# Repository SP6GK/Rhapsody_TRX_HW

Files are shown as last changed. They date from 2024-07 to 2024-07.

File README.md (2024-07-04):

# Rhapsody Project

Rhapsody is an ongoing project focused on the development of a modular amateur radio transceiver. The current version of the project features the zero-IF board, which utilizes two balanced Tayloe mixers to convert 1-30 MHz RF signals into baseband IQ that can be processed by an ADC, and to convert baseband IQ generated by a DAC into output RF, implementing a simplex HF transceiver.

In this repository, you can find the first module developed for the Rhapsody project - the IQ board. This PCB implements two balanced Tayloe mixers (or product detectors if you prefer) to implement both transmit and receive paths for an SDR transceiver. Together with a microcontroller and ADC+DAC (or a PC with a sound card), you can create a working HF software-defined transceiver. Special care was put into the design to provide the best IQ balance for superb opposite sideband attenuation.

I have presented more measurements and theory of operation on my personal website: [Description of Rhapsody project on SP6GK.com](https://www.sp6gk.com/Rhapsody_IQ_Board.html). Bare in mind that these results were possible thanks to low tolerance components in the feedback loops of the op amps and software tuning.

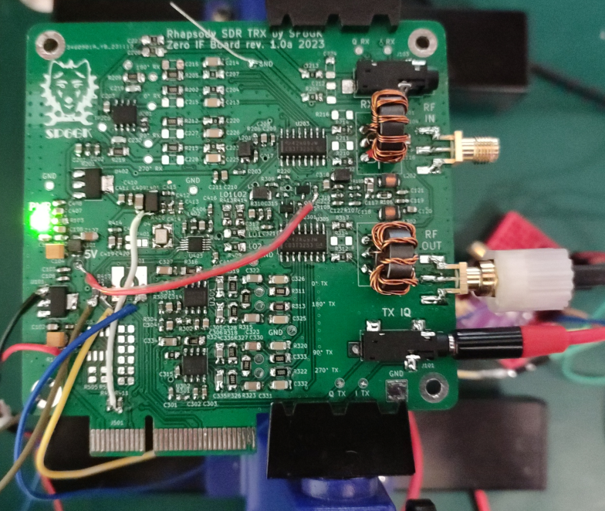
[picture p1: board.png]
Assembled PCB


The current version of the IQ board is designed for testability. Zero Ohm resistors are implemented as jumpers so that different configurations of RF transformers can be tested. If the value of a resistor is not provided, it is most likely not to be populated (DNP). On the other hand, the zero-Ohm resistors indicate the default option.
RF transformers were wound on FT37-43.

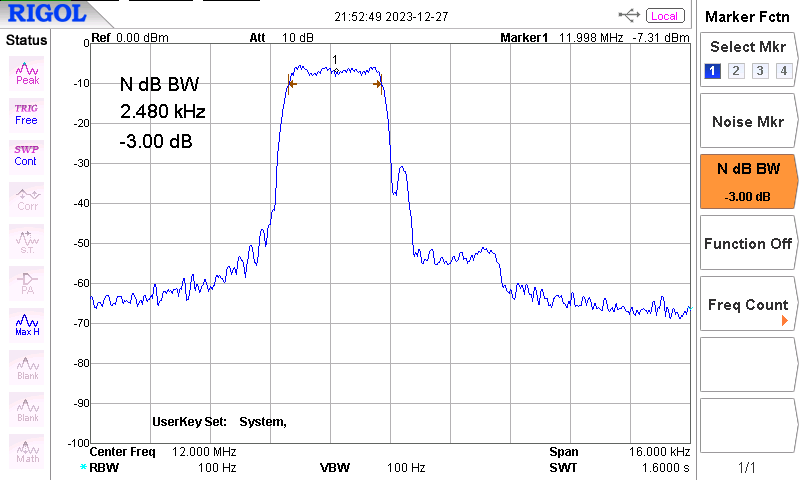
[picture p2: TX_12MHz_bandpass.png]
Single tone SSB at 12 MHz TX

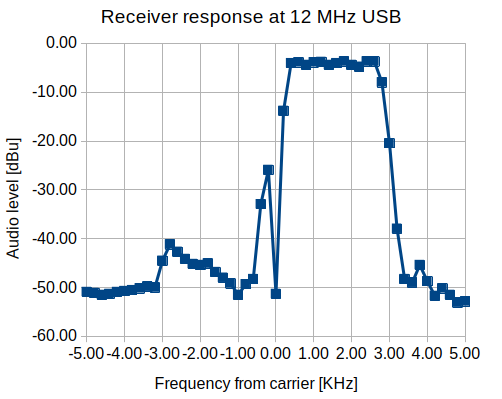
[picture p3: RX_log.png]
Receiver selectivity


The above results were obtained with my software running on an STM32F407 with a 24-bit 48 KHz ADC/DAC on the I2S interface. [Link to software repository](https://github.com/SP6GK/Rhapsody_TRX_SW)

**Experimental features include:**
- Option to include an additional active LPF in the IQ signal path before the ADC (better spurious image rejection and better anti-aliasing, but may cause worse IQ imbalance; not tested yet)
- Additional passive RC LPF before the RX op amps
- 2.5V reference created by impedance buffer - higher current output for the 2.5V rail should provide even better stability
- External oscillator can be used with a single-ended input. A Johnson Counter then creates an IQ LO. This solution limits the operating frequency to 1/4 of the maximum frequency of the 74xx74 chip used. The onboard PLL can provide an LO signal up to 100 MHz, and its reference is a TCXO or a simple crystal.

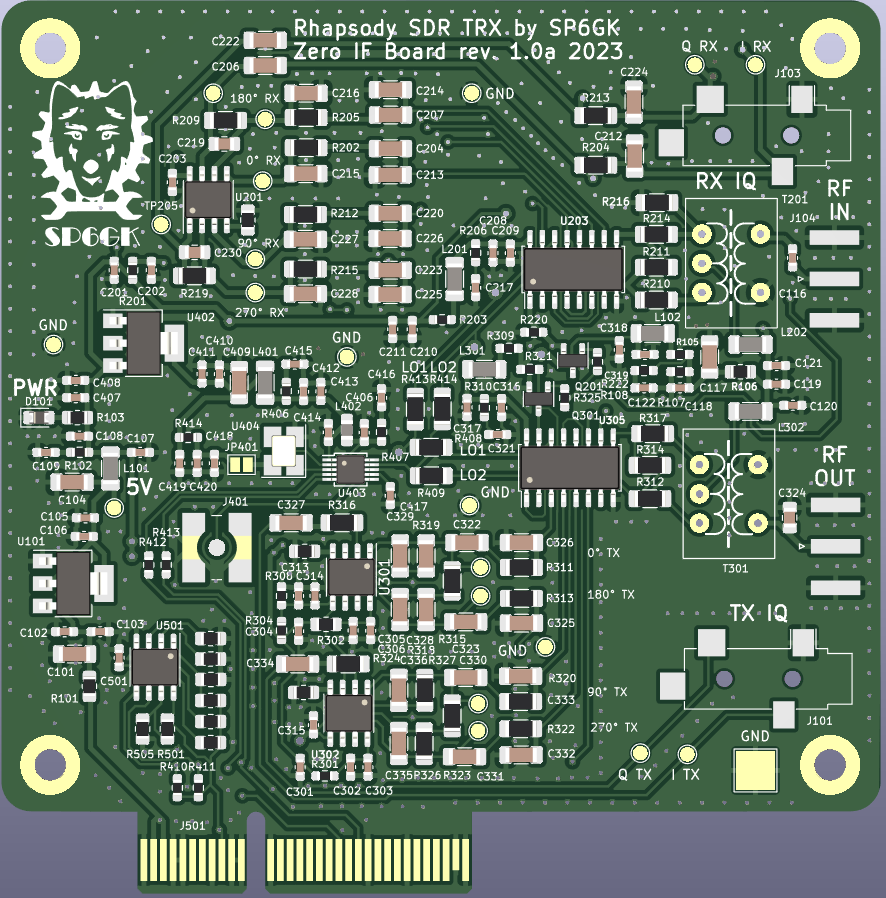
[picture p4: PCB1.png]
Front of the PCB

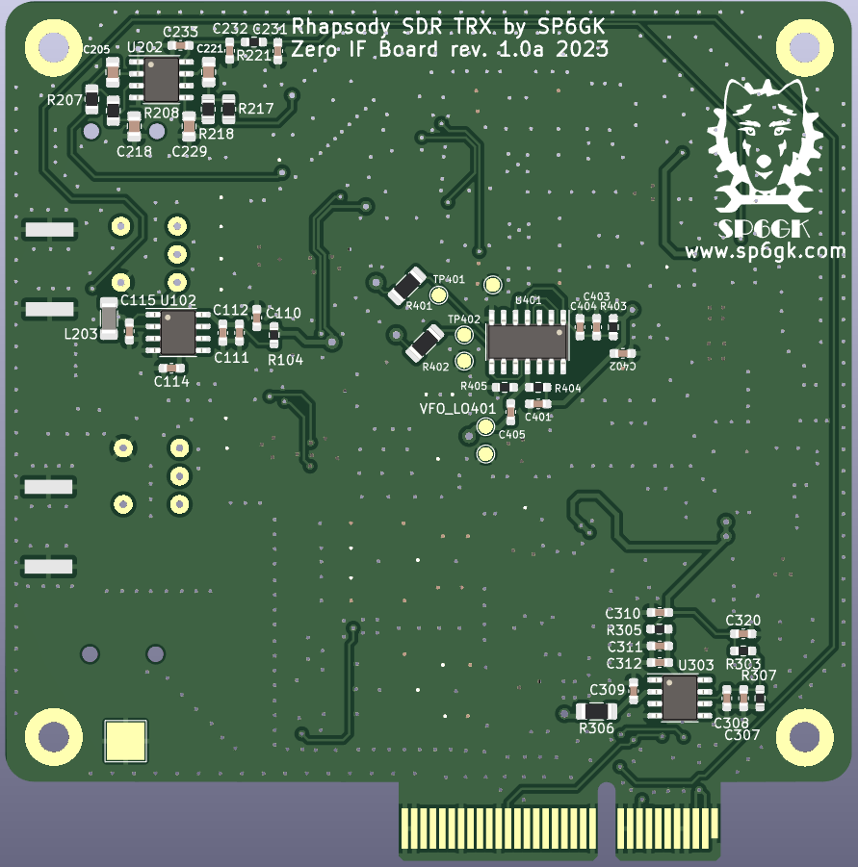
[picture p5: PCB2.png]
Back of the PCB


**How does it work?**
I recommend the following resources if you want to understand more about the hardware behind this project:
- **Best place to learn about the Tayloe mixer** by Dan Tayloe, [Ultra Low Noise, High Performance, Zero IF Quadrature Product Detector and Preamplifier](https://norcalqrp.org/files/Tayloe_mixer_x3a.pdf)
- **Further description of SDR** by Gerald Youngblood, [A Software-Defined Radio for the Masses](https://www.arrl.org/files/file/Technology/tis/info/pdf/020708qex013.pdf)

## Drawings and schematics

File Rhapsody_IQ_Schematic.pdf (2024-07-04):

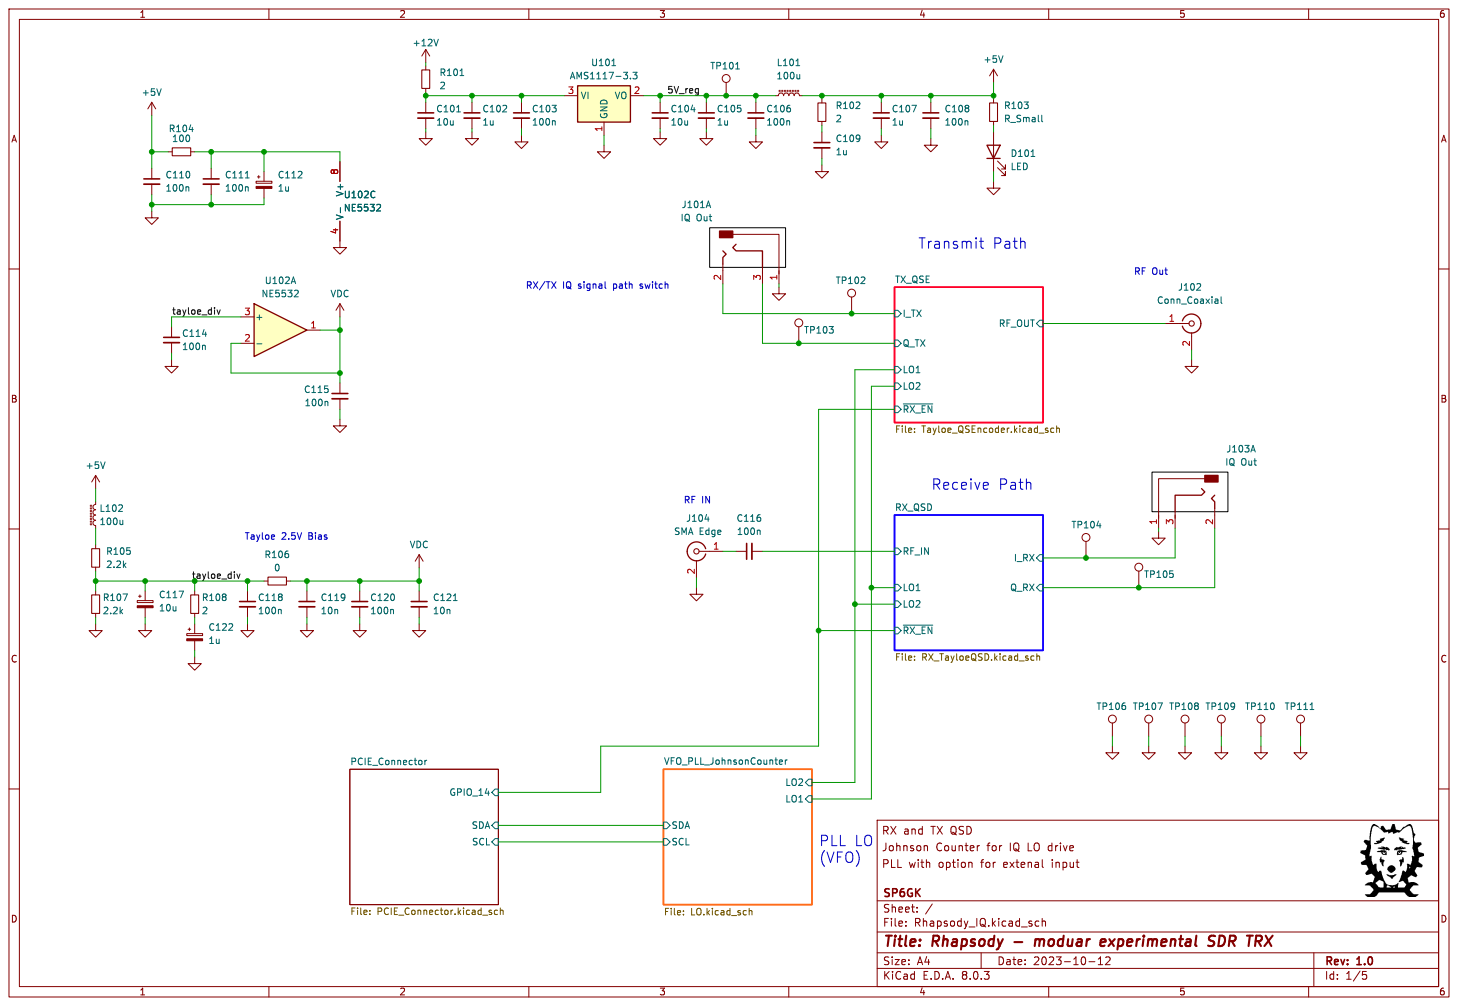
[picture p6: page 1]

RX/TX IQ signal path switch

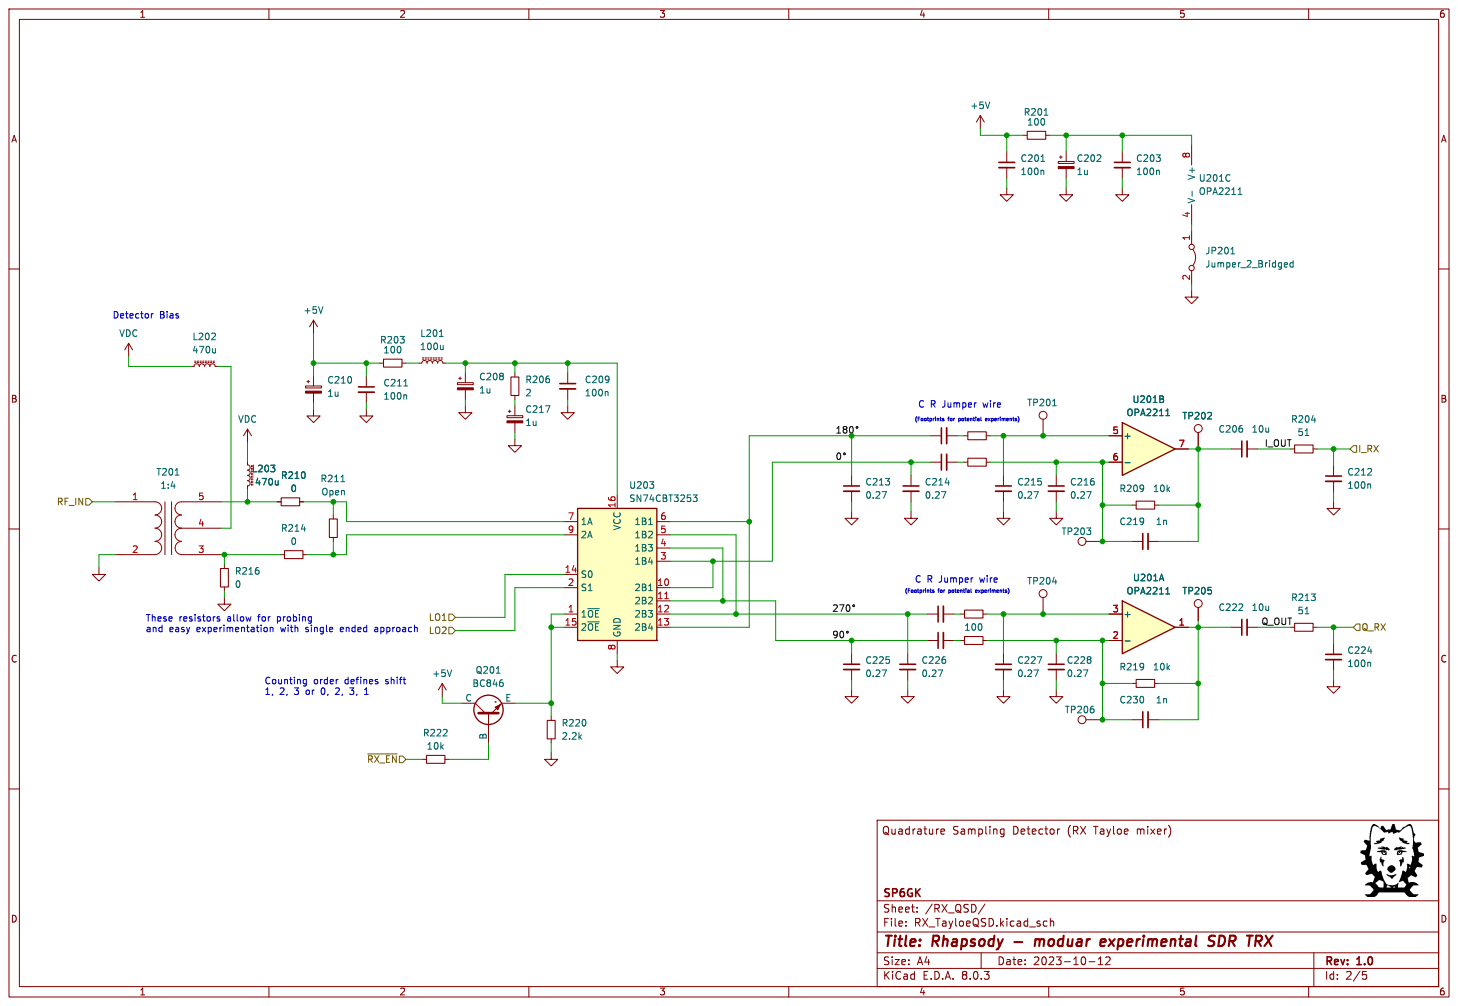
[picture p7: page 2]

Counting order defines shift 1, 2, 3 or 0, 2, 3, 1

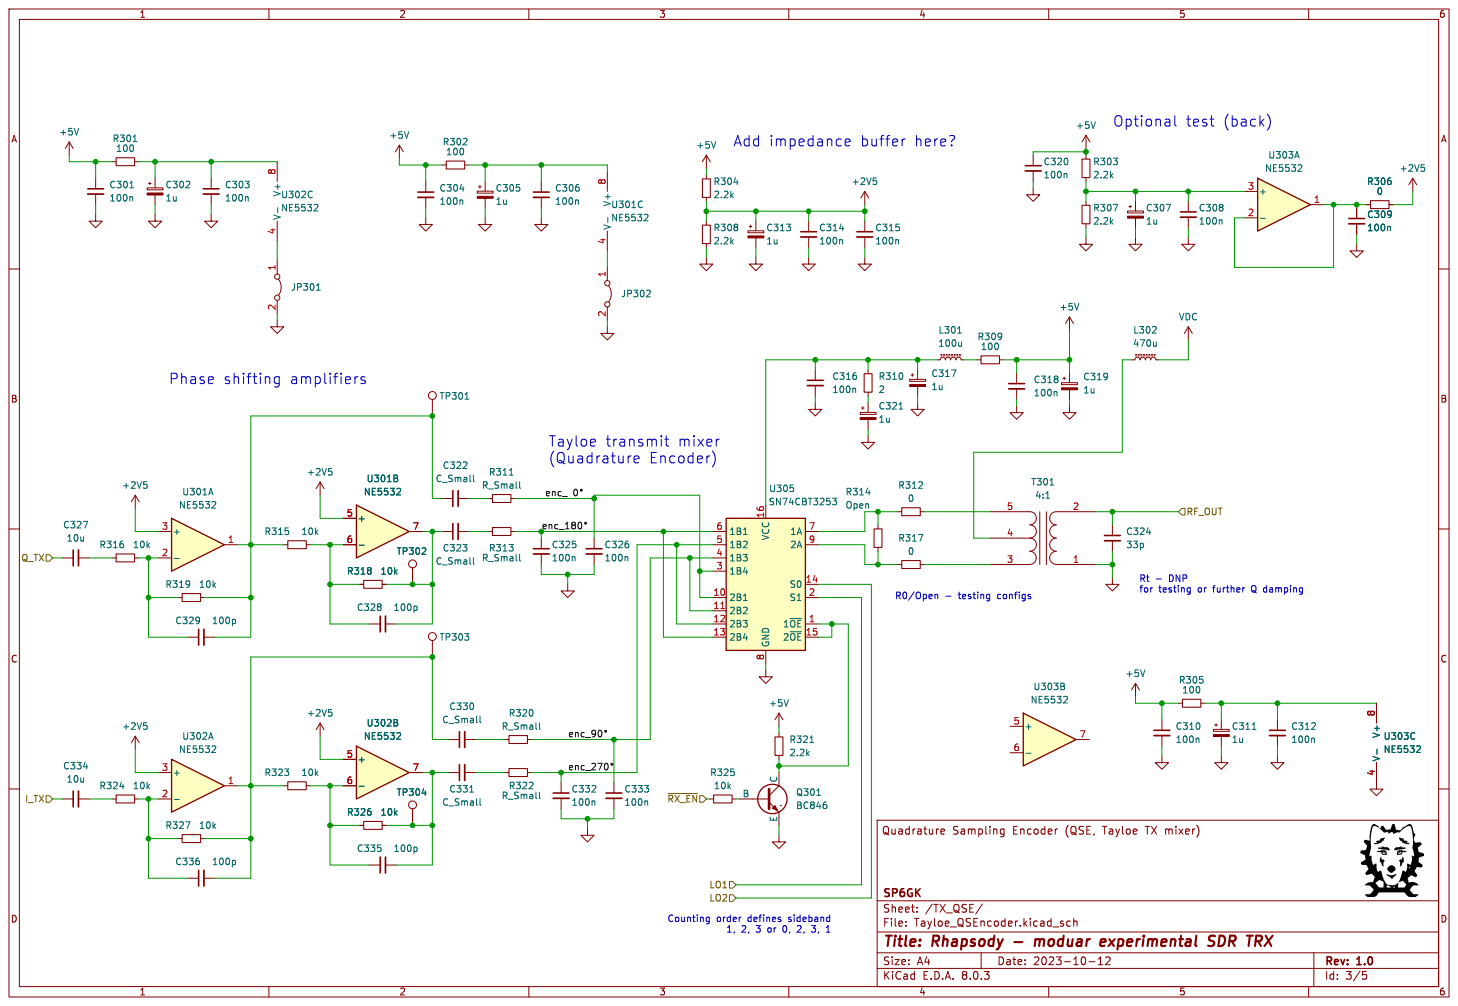
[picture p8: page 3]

for testing or further Q damping

Counting order defines sideband

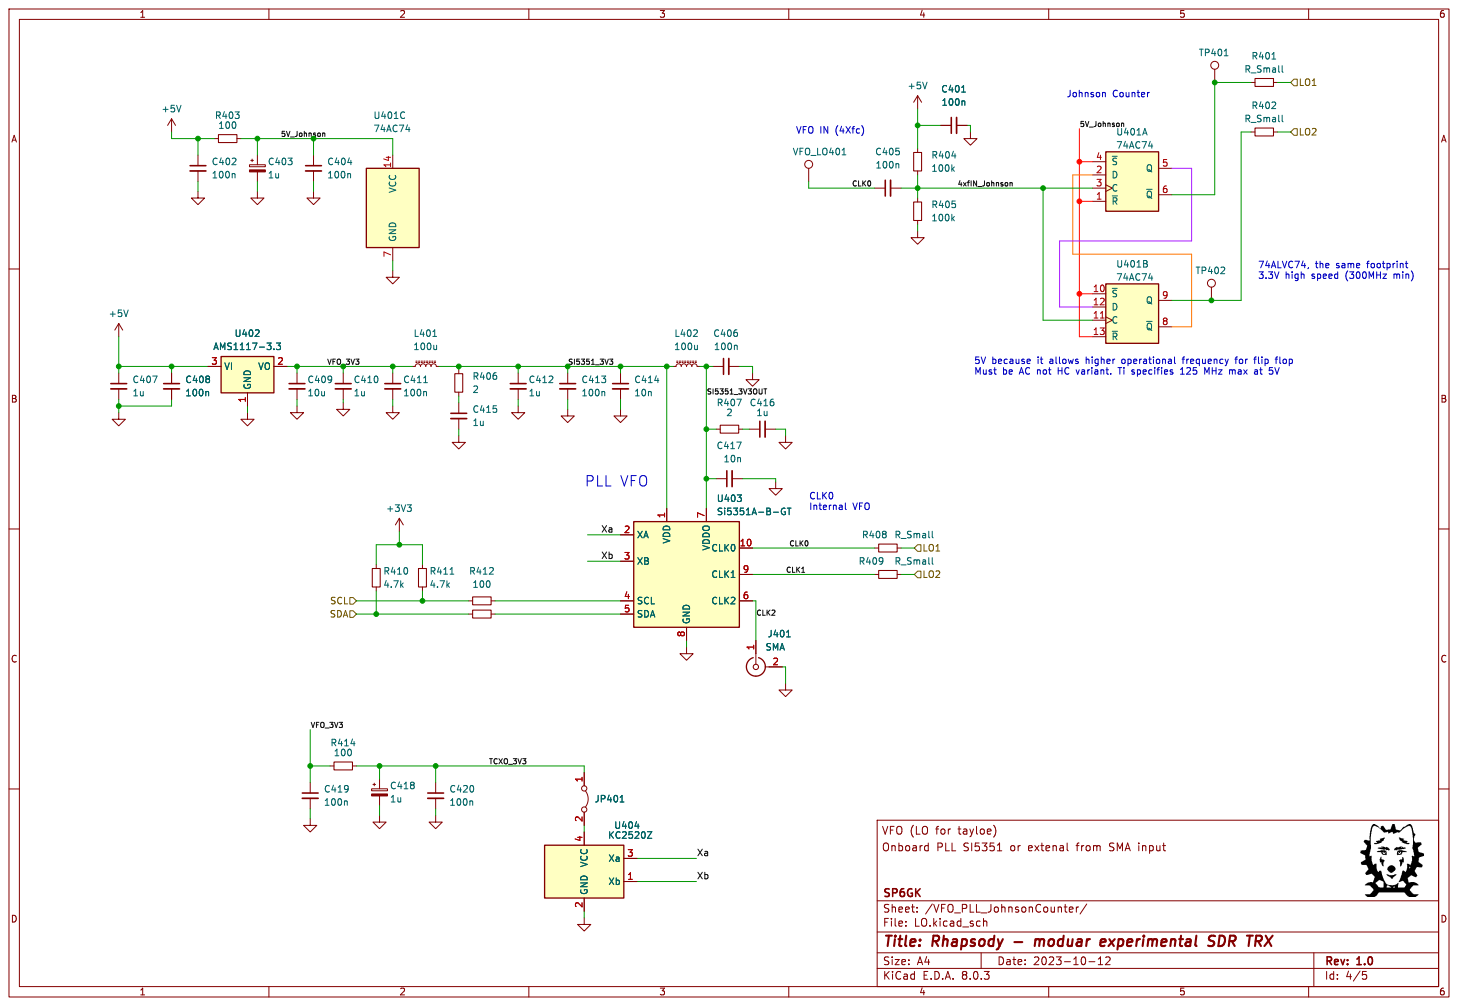
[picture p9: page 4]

74ALVC74, the same footprint 3.3V high speed (300MHz min) Johnson Counter PLL VFO

1 CLK0 10 XA 2 XB 3 SCL 4 SDA 5 CLK2 6 VDDO

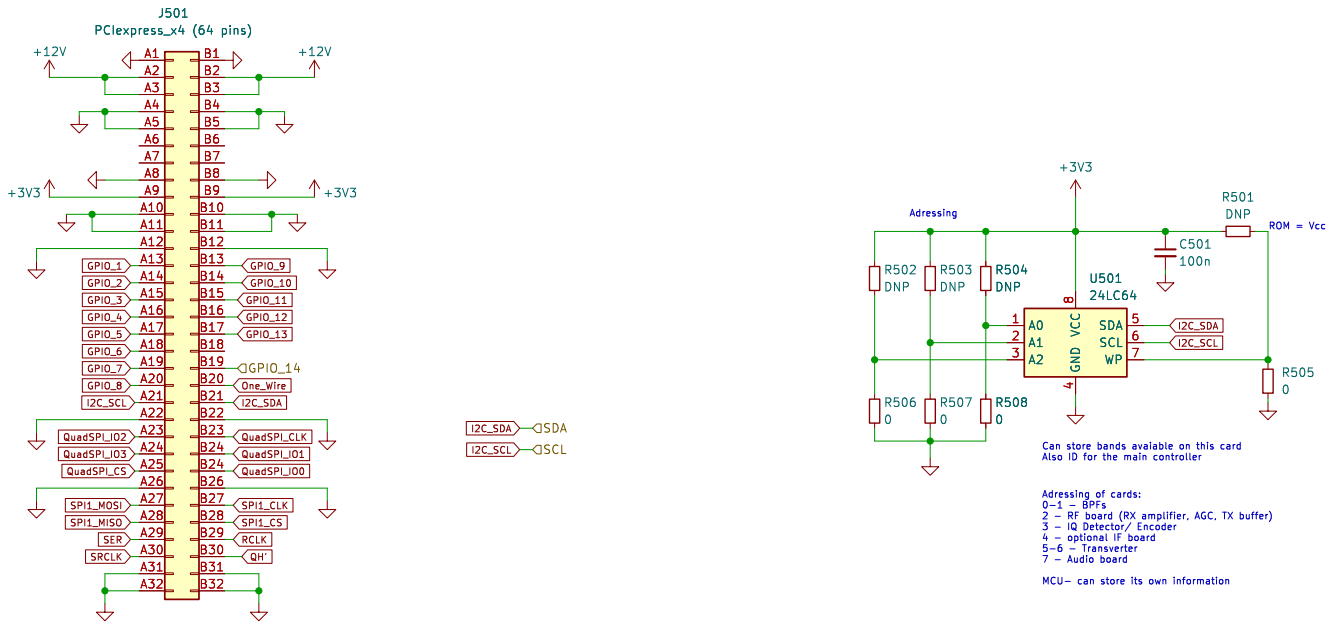
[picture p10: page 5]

4 SDA 5 SCL 6 WP 7 VCC

Id: 5/5 Title: File: PCIE_Connector.kicad_sch Sheet: /PCIE_Connector/

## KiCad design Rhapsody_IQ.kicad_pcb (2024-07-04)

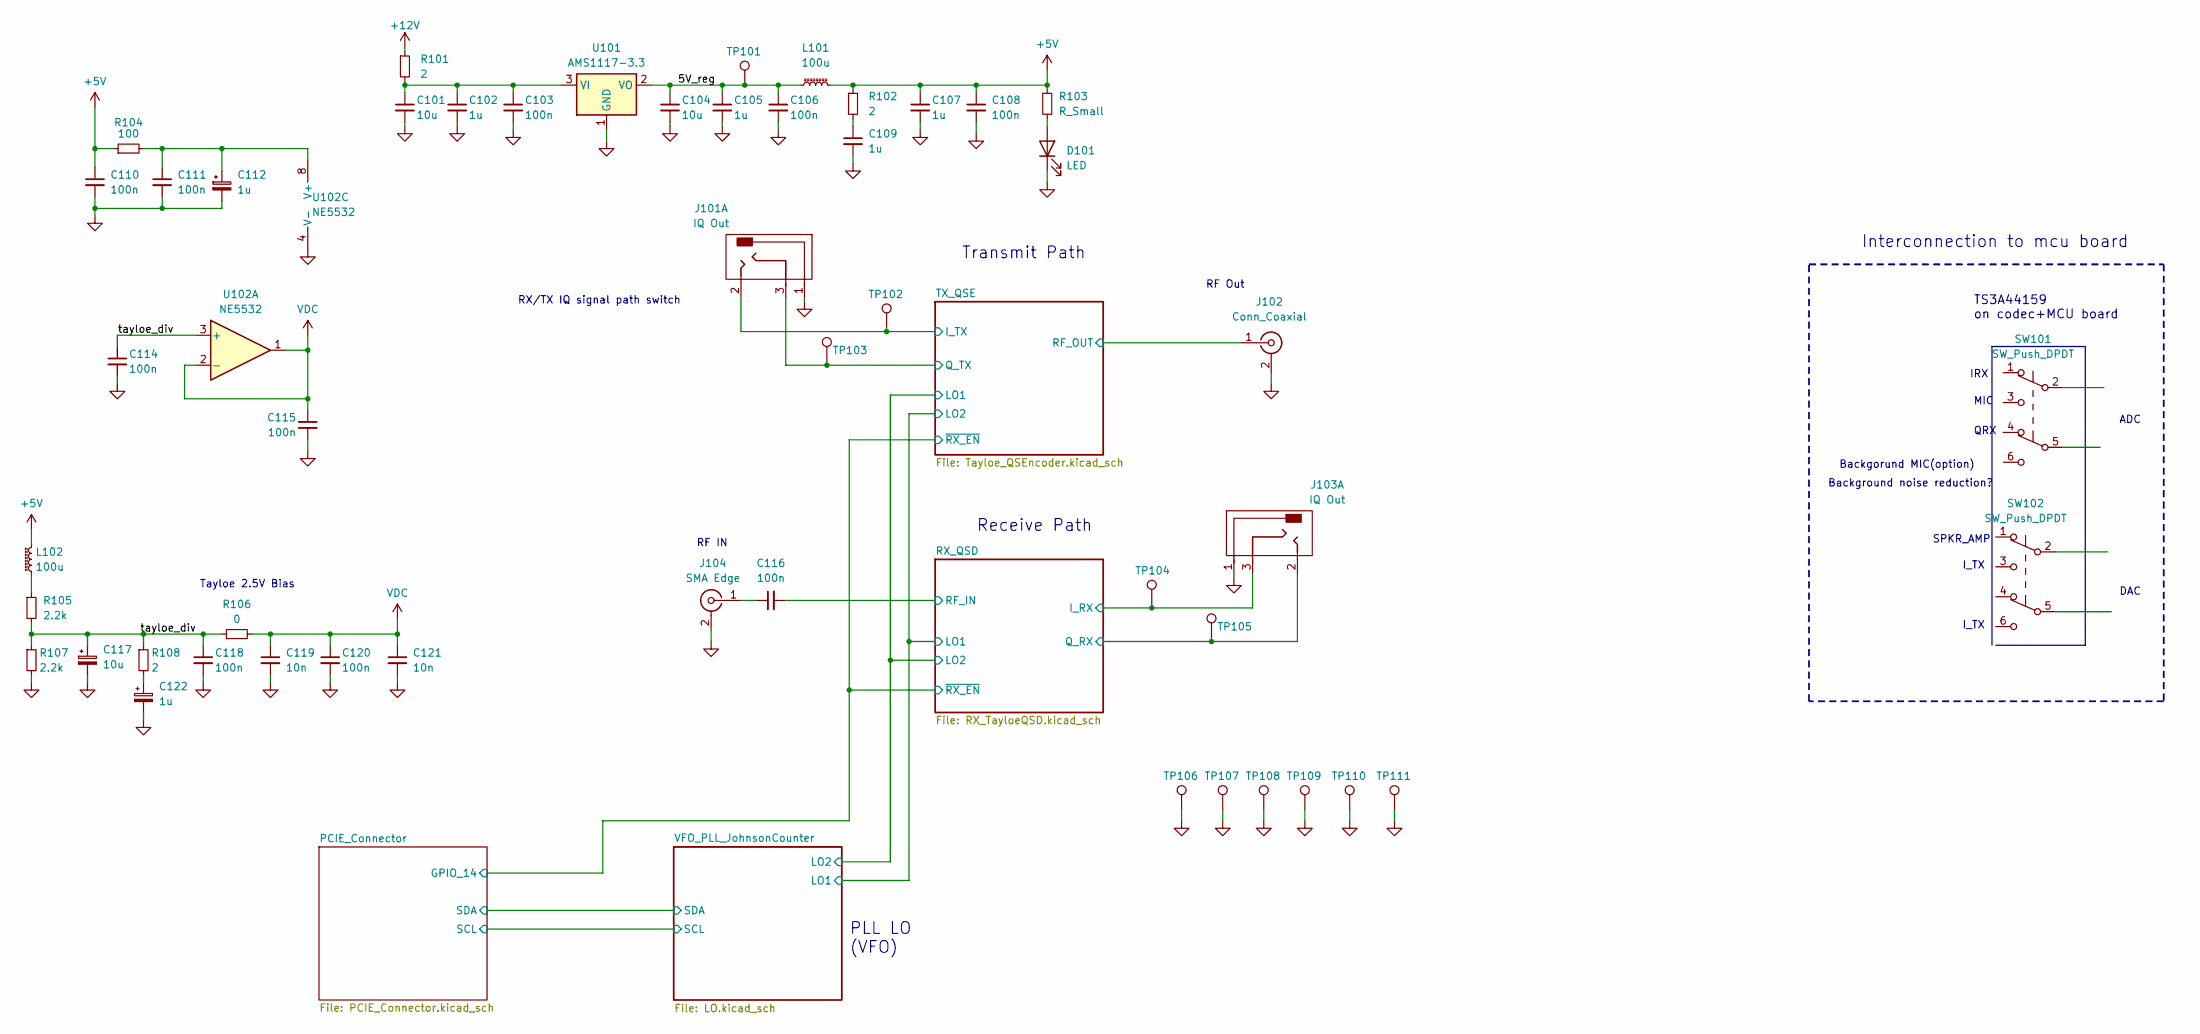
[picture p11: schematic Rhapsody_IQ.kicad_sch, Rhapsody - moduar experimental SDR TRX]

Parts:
C101, C104, C117: 10u; C_1206_3216Metric_Pad1.33x1.80mm_HandSolder
C102, C105, C107, C109, C112, C122: 1u; C_0603_1608Metric_Pad1.08x0.95mm_HandSolder
C103, C106, C108, C110, C111, C114, C115, C116, C118, C120: 100n; C_0603_1608Metric_Pad1.08x0.95mm_HandSolder
C119, C121: 10n; C_0603_1608Metric_Pad1.08x0.95mm_HandSolder
D101: LED; D_0805_2012Metric_Pad1.15x1.40mm_HandSolder
J101, J103: IQ Out; Jack_3.5mm_CUI_SJ-3524-SMT_Horizontal
J102: Conn_Coaxial; SMA_Amphenol_132289_EdgeMount
J104: SMA Edge; SMA_Amphenol_132289_EdgeMount
L101, L102: 100u; L_1206_3216Metric_Pad1.22x1.90mm_HandSolder
R101: 2; R_0805_2012Metric_Pad1.20x1.40mm_HandSolder
R102, R108: 2; R_0603_1608Metric_Pad0.98x0.95mm_HandSolder
R103: R_Small; R_0805_2012Metric_Pad1.20x1.40mm_HandSolder
R104: 100; R_0603_1608Metric_Pad0.98x0.95mm_HandSolder
R105, R107: 2.2k; R_0603_1608Metric_Pad0.98x0.95mm_HandSolder
R106: 0; R_0805_2012Metric_Pad1.20x1.40mm_HandSolder
SW101, SW102: SW_Push_DPDT
TP101, TP102, TP103, TP104, TP105, TP106, TP107, TP108, TP109: TestPoint; TestPoint_Pad_D1.5mm
TP110, TP111: TestPoint; TestPoint_Pad_4.0x4.0mm
U101: AMS1117-3.3; SOT-223-3_TabPin2
U102: NE5532; SOIC-8_3.9x4.9mm_P1.27mm

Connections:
+5V: C107.1, C108.1, C110.1, L101.2, L102.2, R102.1, R103.1, R104.1; also elsewhere on the board
+12V: R101.1; also elsewhere on the board
/5V_reg: C104.1, C105.1, C106.1, L101.1, TP101.1, U101.2 (VO)
/RX_QSD/I_RX: J103.3, TP104.1; also elsewhere on the board
/RX_QSD/Q_RX: J103.2, TP105.1; also elsewhere on the board
/RX_QSD/RF_IN: C116.2; also elsewhere on the board
/TX_QSE/I_TX: J101.2, TP102.1; also elsewhere on the board
/TX_QSE/Q_TX: J101.3, TP103.1; also elsewhere on the board
/TX_QSE/RF_OUT: J102.1 (In); also elsewhere on the board
/tayloe_div: C114.1, C117.1, C118.1, R105.2, R106.1, R107.1, R108.1, U102.3 (+)
GND: C101.2, C102.2, C103.2, C104.2, C105.2, C106.2, C107.2, C108.2, C109.2, C110.2, C111.2, C112.2, C114.2, C115.2, C117.2, C118.2, C119.2, C120.2, C121.2, C122.2, D101.1 (K), J101.1, J102.2 (Ext), J103.1, J104.2 (Ext), R107.2, TP106.1, TP107.1, TP108.1, TP109.1, TP110.1, TP111.1, U101.1 (GND), U102.4 (V-); also elsewhere on the board
unnamed: C109.1, R102.2
unnamed: C122.1, R108.2
unnamed: D101.2 (A), R103.2
unnamed: C116.1, J104.1 (In)
unnamed: L102.1, R105.1
unnamed: C101.1, C102.1, C103.1, R101.2, U101.3 (VI)
unnamed: C111.1, C112.1, R104.2, U102.8 (V+)
VDC: C115.1, C119.1, C120.1, C121.1, R106.2, U102.1, U102.2 (-); also elsewhere on the board

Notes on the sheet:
RF IN
DAC
Interconnection to mcu board
Backgorund MIC(option)
RF Out
RX/TX IQ signal path switch
Receive Path
Background noise reduction?
I_TX
SPKR_AMP
ADC
PLL LO (VFO)
TS3A44159 on codec+MCU board
IRX
Transmit Path
Tayloe 2.5V Bias
MIC
QRX

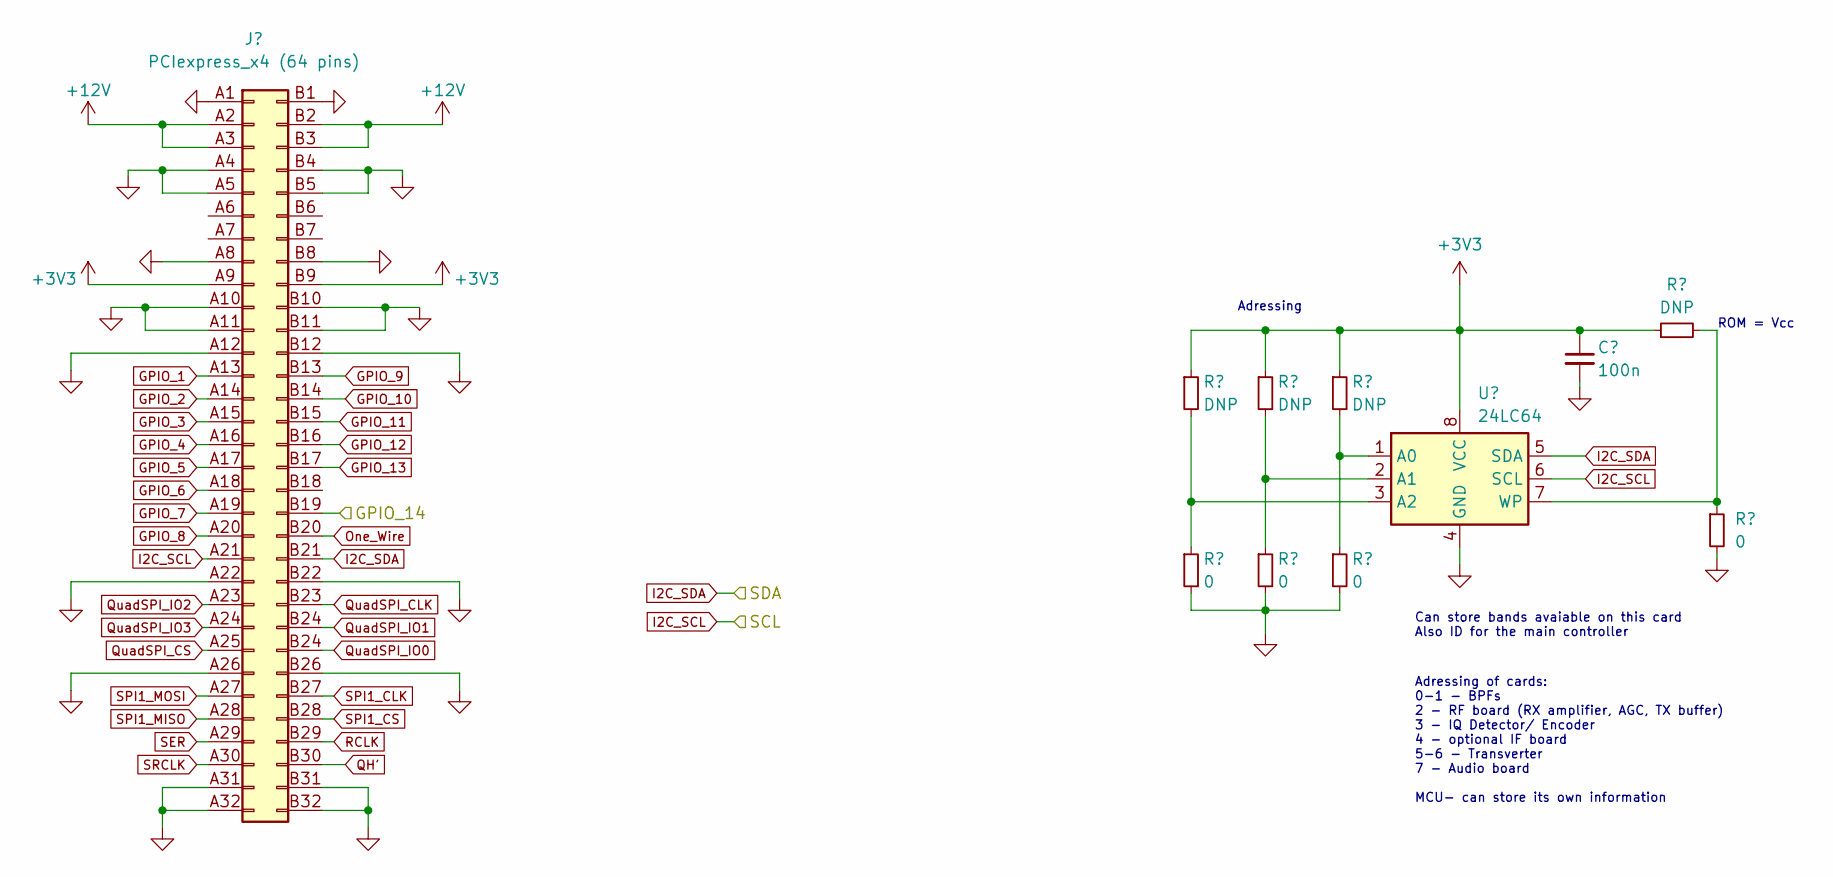
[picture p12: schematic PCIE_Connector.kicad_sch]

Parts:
C501: 100n; C_0603_1608Metric_Pad1.08x0.95mm_HandSolder
J501: PCIexpress_x4 (64 pins); BUS_PCIexpress_x4
R501, R502, R503, R504: DNP; R_0805_2012Metric_Pad1.20x1.40mm_HandSolder
R505, R506, R507, R508: 0; R_0805_2012Metric_Pad1.20x1.40mm_HandSolder
U501: 24LC64; SOIC-8_3.9x4.9mm_P1.27mm

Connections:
+3V3: C501.1, J501.A9 (Pin_9), J501.B9 (Pin_56), R501.1, R502.1, R503.1, R504.1, U501.8 (VCC); also elsewhere on the board
+12V: J501.A2 (Pin_2), J501.A3 (Pin_3), J501.B2 (Pin_63), J501.B3 (Pin_62); also elsewhere on the board
/PCIE_Connector/GPIO_14: J501.B19 (Pin_46); also elsewhere on the board
GND: C501.2, J501.A1 (Pin_1), J501.A4 (Pin_4), J501.A5 (Pin_5), J501.A8 (Pin_8), J501.A10 (Pin_10), J501.A11 (Pin_11), J501.A12 (Pin_12), J501.A22 (Pin_22), J501.A26 (Pin_26), J501.A31 (Pin_31), J501.A32 (Pin_32), J501.B1 (Pin_64), J501.B4 (Pin_61), J501.B5 (Pin_60), J501.B8 (Pin_57), J501.B10 (Pin_55), J501.B11 (Pin_54), J501.B12 (Pin_53), J501.B22 (Pin_43), J501.B26 (Pin_39), J501.B31 (Pin_31), J501.B32 (Pin_33), R505.2, R506.2, R507.2, R508.2, U501.4 (GND); also elsewhere on the board
GPIO_1: J501.A13 (Pin_13)
GPIO_2: J501.A14 (Pin_14)
GPIO_3: J501.A15 (Pin_15)
GPIO_4: J501.A16 (Pin_16)
GPIO_5: J501.A17 (Pin_17)
GPIO_6: J501.A18 (Pin_18)
GPIO_7: J501.A19 (Pin_19)
GPIO_8: J501.A20 (Pin_20)
GPIO_9: J501.B13 (Pin_52)
GPIO_10: J501.B14 (Pin_51)
GPIO_11: J501.B15 (Pin_50)
GPIO_12: J501.B16 (Pin_49)
GPIO_13: J501.B17 (Pin_48)
I2C_SCL: J501.A21 (Pin_21), U501.6 (SCL); also elsewhere on the board
unnamed: R504.2, R508.1, U501.1 (A0)
unnamed: R503.2, R507.1, U501.2 (A1)
unnamed: R502.2, R506.1, U501.3 (A2)
unnamed: R501.2, R505.1, U501.7 (WP)
One_Wire: J501.B20 (Pin_45)
QH': J501.B30 (Pin_35)
QuadSPI_CLK: J501.B23 (Pin_42)
QuadSPI_CS: J501.A25 (Pin_25)
QuadSPI_IO2: J501.A23 (Pin_23)
QuadSPI_IO3: J501.A24 (Pin_24)
RCLK: J501.B29 (Pin_36)
SER: J501.A29 (Pin_29)
SPI1_CLK: J501.B27 (Pin_38)
SPI1_CS: J501.B28 (Pin_37)
SPI1_MISO: J501.A28 (Pin_28)
SPI1_MOSI: J501.A27 (Pin_27)
SRCLK: J501.A30 (Pin_30)

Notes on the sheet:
Adressing
Can store bands avaiable on this card Also ID for the main controller
Adressing of cards: 0-1 - BPFs 2 - RF board (RX amplifier, AGC, TX buffer) 3 - IQ Detector/ Encoder 4 - optional IF board 5-6 - Transverter 7 - Audio board MCU- can store its own information
ROM = Vcc

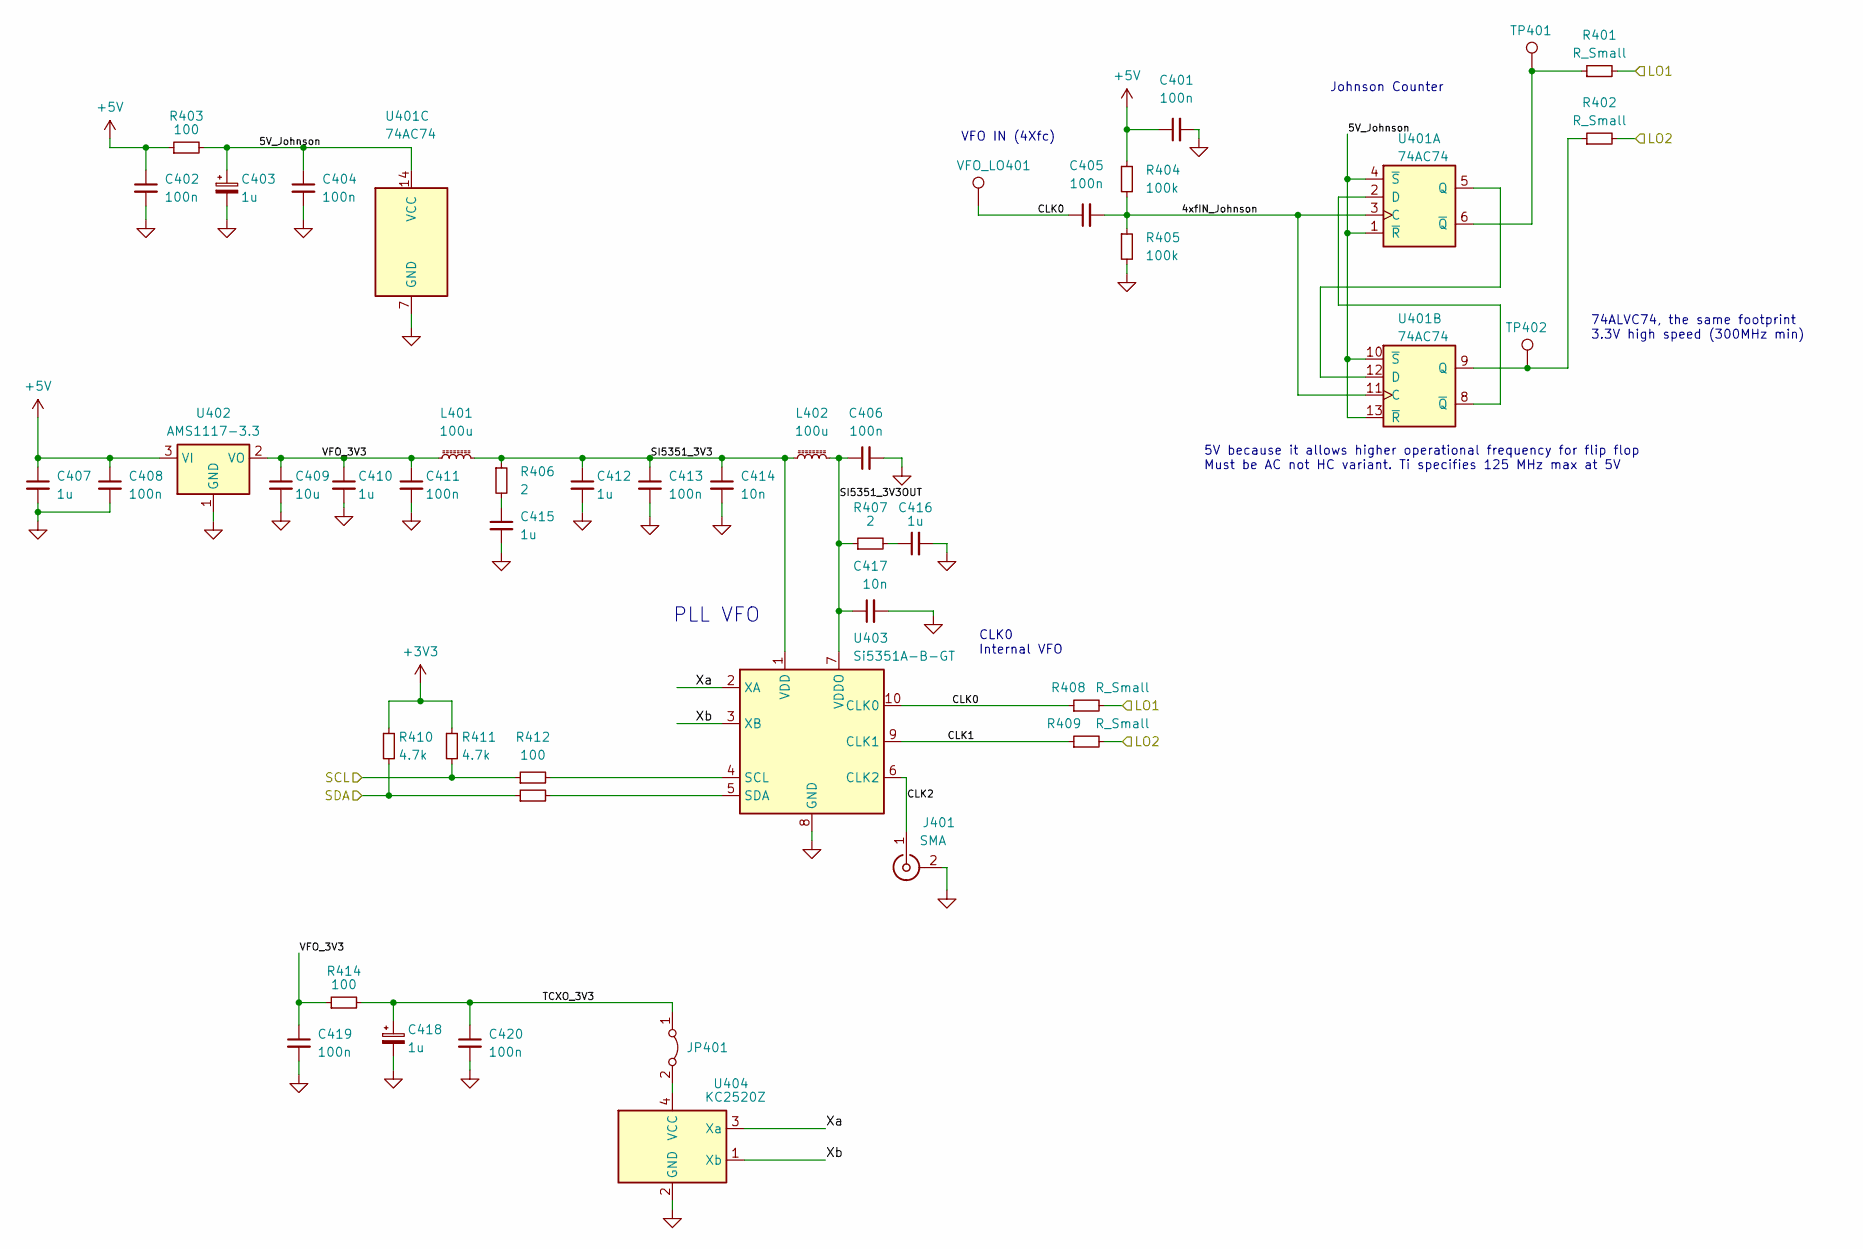
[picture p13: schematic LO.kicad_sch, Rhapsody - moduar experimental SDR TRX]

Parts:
C401, C402, C404, C405, C406, C408, C411, C413, C419, C420: 100n; C_0603_1608Metric_Pad1.08x0.95mm_HandSolder
C403, C407, C410, C412, C415, C416, C418: 1u; C_0603_1608Metric_Pad1.08x0.95mm_HandSolder
C409: 10u; C_1206_3216Metric_Pad1.33x1.80mm_HandSolder
C414, C417: 10n; C_0603_1608Metric_Pad1.08x0.95mm_HandSolder
J401: SMA; SMA_Wurth_60312102114405_Vertical
JP401: Jumper_2_Bridged; SolderJumper-2_P1.3mm_Open_Pad1.0x1.5mm
L401: 100u; L_1206_3216Metric_Pad1.22x1.90mm_HandSolder
L402: 100u; L_0805_2012Metric_Pad1.05x1.20mm_HandSolder
R401, R402, R408, R409: R_Small; R_1206_3216Metric_Pad1.30x1.75mm_HandSolder
R403, R412, R414: 100; R_0603_1608Metric_Pad0.98x0.95mm_HandSolder
R404, R405: 100k; R_0603_1608Metric_Pad0.98x0.95mm_HandSolder
R406, R407: 2; R_0603_1608Metric_Pad0.98x0.95mm_HandSolder
R410, R411: 4.7k; R_0603_1608Metric_Pad0.98x0.95mm_HandSolder
R413: R_Small; R_0603_1608Metric_Pad0.98x0.95mm_HandSolder
TP401, TP402: TestPoint; TestPoint_Pad_D1.5mm
U401: 74AC74; SO-14_3.9x8.65mm_P1.27mm
U402: AMS1117-3.3; SOT-223-3_TabPin2
U403: Si5351A-B-GT; MSOP-10_3x3mm_P0.5mm
U404: KC2520Z; Crystal_SMD_3225-4Pin_3.2x2.5mm_HandSoldering
VFO_LO401: TestPoint; TestPoint_Pad_D1.5mm

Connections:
+3V3: R410.1, R411.1; also elsewhere on the board
+5V: C401.1, C402.1, C407.1, C408.1, R403.1, R404.1, U402.3 (VI); also elsewhere on the board
/VFO_PLL_JohnsonCounter/4xfIN_Johnson: C405.2, R404.2, R405.1, U401.3 (C), U401.11 (C)
/VFO_PLL_JohnsonCounter/5V_Johnson: C403.1, C404.1, R403.2, U401.1 (~R), U401.4 (~S), U401.10 (~S), U401.13 (~R), U401.14 (VCC)
/VFO_PLL_JohnsonCounter/CLK2: J401.1 (In), U403.6 (CLK2)
/VFO_PLL_JohnsonCounter/SI5351_3V3: C412.1, C413.1, C414.1, L401.2, L402.1, R406.1, U403.1 (VDD)
/VFO_PLL_JohnsonCounter/SI5351_3V3OUT: C406.1, C417.1, L402.2, R407.1, U403.7 (VDDO)
/VFO_PLL_JohnsonCounter/Xa: U403.2 (XA), U404.3 (Xa)
/VFO_PLL_JohnsonCounter/Xb: U403.3 (XB), U404.1 (Xb)
GND: C401.2, C402.2, C403.2, C404.2, C406.2, C407.2, C408.2, C409.2, C410.2, C411.2, C412.2, C413.2, C414.2, C415.2, C416.2, C417.2, C418.2, C419.2, C420.2, J401.2 (Ext), R405.2, U401.7 (GND), U402.1 (GND), U403.8 (GND), U404.2 (GND); also elsewhere on the board
I2C_SCL: R411.2, R412.1; also elsewhere on the board
unnamed: C415.1, R406.2
unnamed: C416.1, R407.2
unnamed: JP401.2 (B), U404.4 (VCC)
unnamed: U401.2 (D), U401.8 (~Q)
unnamed: U401.5 (Q), U401.12 (D)
unnamed: R401.1, TP401.1, U401.6 (~Q)
unnamed: R402.1, TP402.1, U401.9 (Q)
unnamed: R412.2, U403.4 (SCL)

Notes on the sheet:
CLK0 Internal VFO
VFO IN (4Xfc)
PLL VFO
Johnson Counter
74ALVC74, the same footprint 3.3V high speed (300MHz min)
5V because it allows higher operational frequency for flip flop Must be AC not HC variant. Ti specifies 125 MHz max at 5V

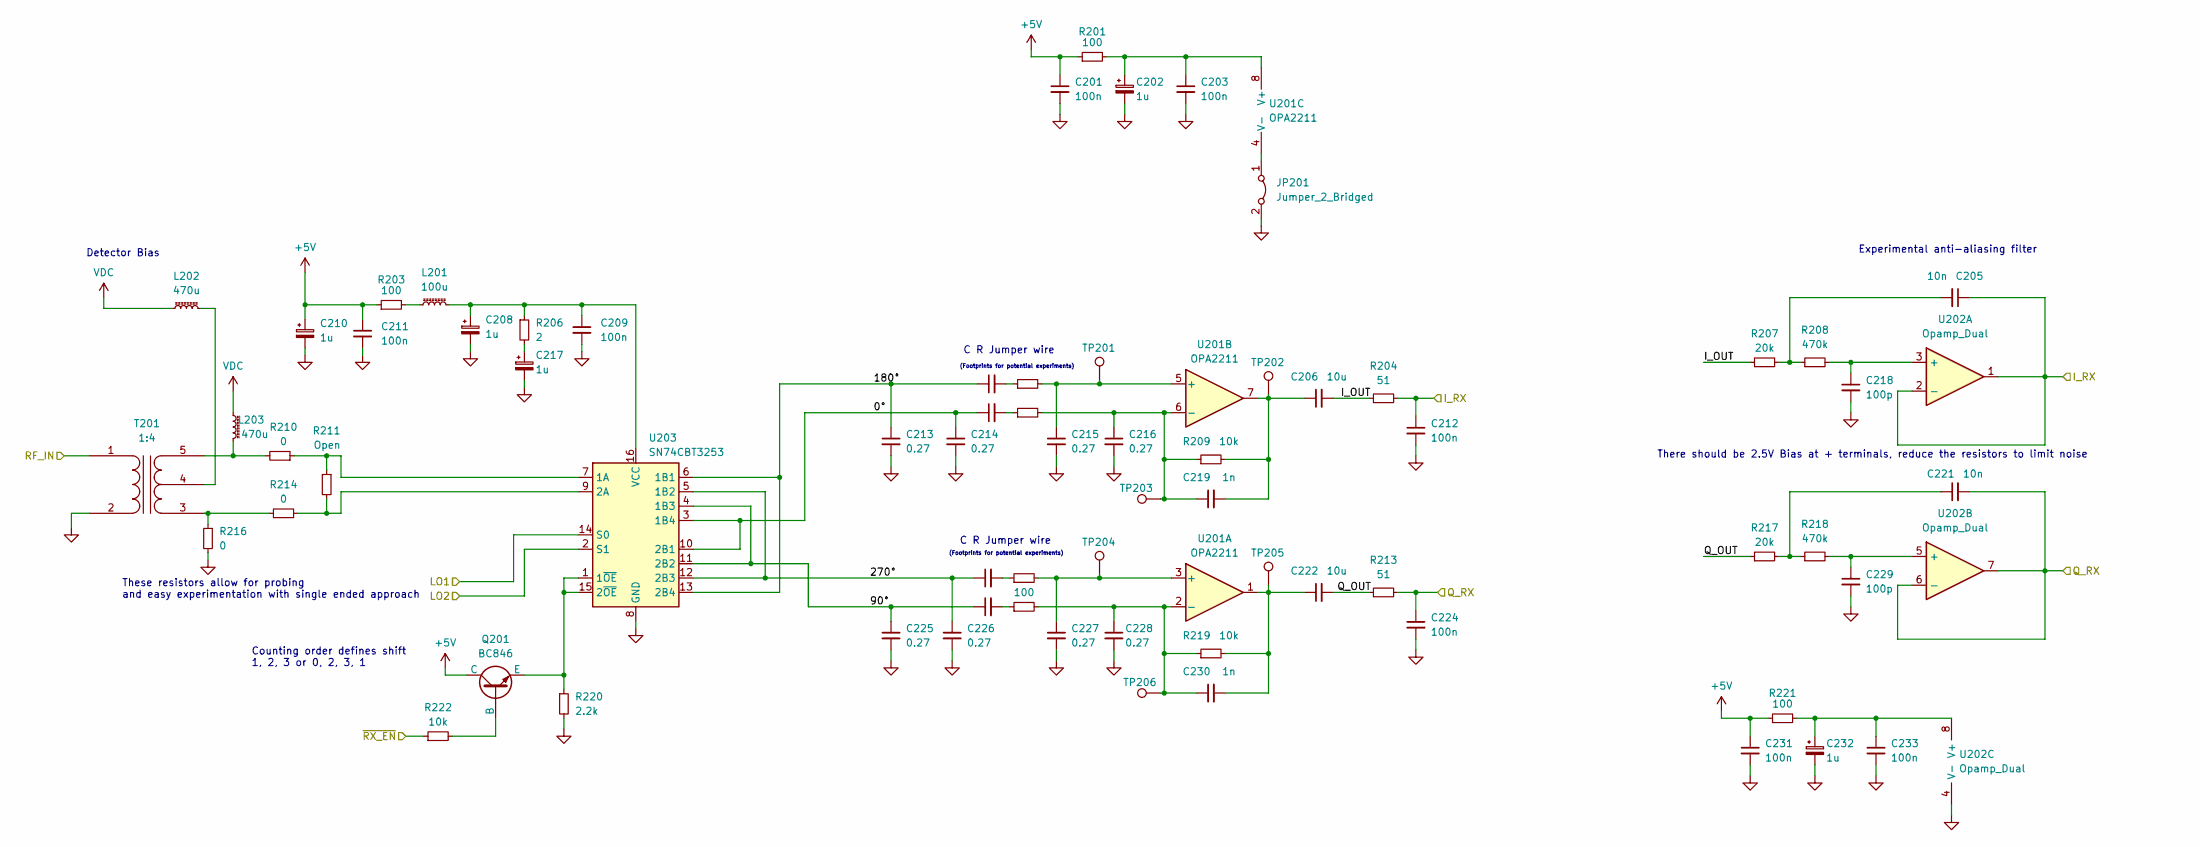
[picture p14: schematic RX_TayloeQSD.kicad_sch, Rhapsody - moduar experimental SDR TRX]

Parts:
C201, C203, C209, C211, C231, C233: 100n; C_0603_1608Metric_Pad1.08x0.95mm_HandSolder
C202, C208, C210, C217, C232: 1u; C_0603_1608Metric_Pad1.08x0.95mm_HandSolder
C204, C206, C207, C220, C222, C223: 10u; C_1206_3216Metric_Pad1.33x1.80mm_HandSolder
C205, C221: 10n; C_0805_2012Metric_Pad1.18x1.45mm_HandSolder
C212, C224: 100n; C_1206_3216Metric_Pad1.33x1.80mm_HandSolder
C213, C214, C215, C216, C225, C226, C227, C228: 0.27; C_1206_3216Metric_Pad1.33x1.80mm_HandSolder
C218, C229: 100p; C_0805_2012Metric_Pad1.18x1.45mm_HandSolder
C219, C230: 1n; C_0805_2012Metric_Pad1.18x1.45mm_HandSolder
JP201: Jumper_2_Bridged; R_0805_2012Metric_Pad1.20x1.40mm_HandSolder
L201: 100u; L_1206_3216Metric_Pad1.22x1.90mm_HandSolder
L202, L203: 470u; L_1206_3216Metric_Pad1.22x1.90mm_HandSolder
Q201: BC846; SOT-23-3
R201, R203, R221: 100; R_0603_1608Metric_Pad0.98x0.95mm_HandSolder
R202, R205, R215: 200; R_1206_3216Metric_Pad1.30x1.75mm_HandSolder
R204, R213: 51; R_1206_3216Metric_Pad1.30x1.75mm_HandSolder
R206: 2; R_0603_1608Metric_Pad0.98x0.95mm_HandSolder
R207, R217: 20k; R_0805_2012Metric_Pad1.20x1.40mm_HandSolder
R208, R218: 470k; R_0805_2012Metric_Pad1.20x1.40mm_HandSolder
R209, R219: 10k; R_1206_3216Metric_Pad1.30x1.75mm_HandSolder
R210, R214, R216: 0; R_1206_3216Metric_Pad1.30x1.75mm_HandSolder
R211: Open; R_1206_3216Metric_Pad1.30x1.75mm_HandSolder
R212: 100; R_1206_3216Metric_Pad1.30x1.75mm_HandSolder
R220: 2.2k; R_0603_1608Metric_Pad0.98x0.95mm_HandSolder
R222: 10k; R_0603_1608Metric_Pad0.98x0.95mm_HandSolder
T201: 1:4; T37_toroid
TP201, TP202, TP203, TP204, TP205, TP206: TestPoint; TestPoint_Pad_D1.5mm
U201: OPA2211; SOIC-8_3.9x4.9mm_P1.27mm
U202: Opamp_Dual; SOIC-8_3.9x4.9mm_P1.27mm
U203: SN74CBT3253; SOIC-16_4.55x10.3mm_P1.27mm

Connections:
+5V: C201.1, C210.1, C211.1, C231.1, Q201.3 (C), R201.1, R203.1, R221.1; also elsewhere on the board
/PCIE_Connector/GPIO_14: R222.1; also elsewhere on the board
/RX_QSD/0°: C207.1, C214.1, U203.3 (1B4), U203.10 (2B1)
/RX_QSD/90°: C223.1, C225.1, U203.4 (1B3), U203.11 (2B2)
/RX_QSD/180°: C204.1, C213.1, U203.6 (1B1), U203.13 (2B4)
/RX_QSD/270°: C220.1, C226.1, U203.5 (1B2), U203.12 (2B3)
/RX_QSD/I_OUT: C206.2, R204.1, R207.1
/RX_QSD/I_RX: C205.1, C212.1, R204.2, U202.1, U202.2 (-); also elsewhere on the board
/RX_QSD/Q_OUT: C222.2, R213.1, R217.1
/RX_QSD/Q_RX: C221.2, C224.1, R213.2, U202.6 (-), U202.7; also elsewhere on the board
/RX_QSD/RF_IN: T201.1 (AA); also elsewhere on the board
GND: C201.2, C202.2, C203.2, C208.2, C209.2, C210.2, C211.2, C212.2, C213.2, C214.2, C215.2, C216.2, C217.2, C218.2, C224.2, C225.2, C226.2, C227.2, C228.2, C229.2, C231.2, C232.2, C233.2, JP201.2 (B), R216.2, R220.2, T201.2 (AB), U202.4 (V-), U203.8 (GND); also elsewhere on the board
unnamed: C204.2, R202.1
unnamed: C205.2, R207.2, R208.1
unnamed: C206.1, C219.2, R209.2, TP202.1, U201.7
unnamed: C207.2, R205.1
unnamed: C217.1, R206.2
unnamed: C220.2, R212.1
unnamed: C221.1, R217.2, R218.1
unnamed: C222.1, C230.2, R219.2, TP205.1, U201.1
unnamed: C223.2, R215.1
unnamed: JP201.1 (A), U201.4 (V-)
unnamed: L201.1, R203.2
unnamed: Q201.1 (B), R222.2
unnamed: Q201.2 (E), R220.1, U203.1 (1~OE), U203.15 (2~OE)
unnamed: R214.2, R216.1, T201.3 (SA)
unnamed: L203.2, R210.2, T201.5 (SB)
unnamed: L202.2, T201.4 (SC)
unnamed: C227.1, R212.2, TP204.1, U201.3 (+)
unnamed: C228.1, C230.1, R215.2, R219.1, TP206.1, U201.2 (-)
unnamed: C215.1, R202.2, TP201.1, U201.5 (+)
unnamed: C216.1, C219.1, R205.2, R209.1, TP203.1, U201.6 (-)
unnamed: C202.1, C203.1, R201.2, U201.8 (V+)
unnamed: C218.1, R208.2, U202.3 (+)
unnamed: C229.1, R218.2, U202.5 (+)
unnamed: C232.1, C233.1, R221.2, U202.8 (V+)
unnamed: R210.1, R211.1, U203.7 (1A)
unnamed: R211.2, R214.1, U203.9 (2A)
unnamed: C208.1, C209.1, L201.2, R206.1, U203.16 (VCC)
VDC: L202.1, L203.1; also elsewhere on the board

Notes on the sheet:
Counting order defines shift 1, 2, 3 or 0, 2, 3, 1
There should be 2.5V Bias at + terminals, reduce the resistors to limit noise
These resistors allow for probing and easy experimentation with single ended approach
Detector Bias
Experimental anti-aliasing filter
C R Jumper wire
(Footprints for potential experiments)

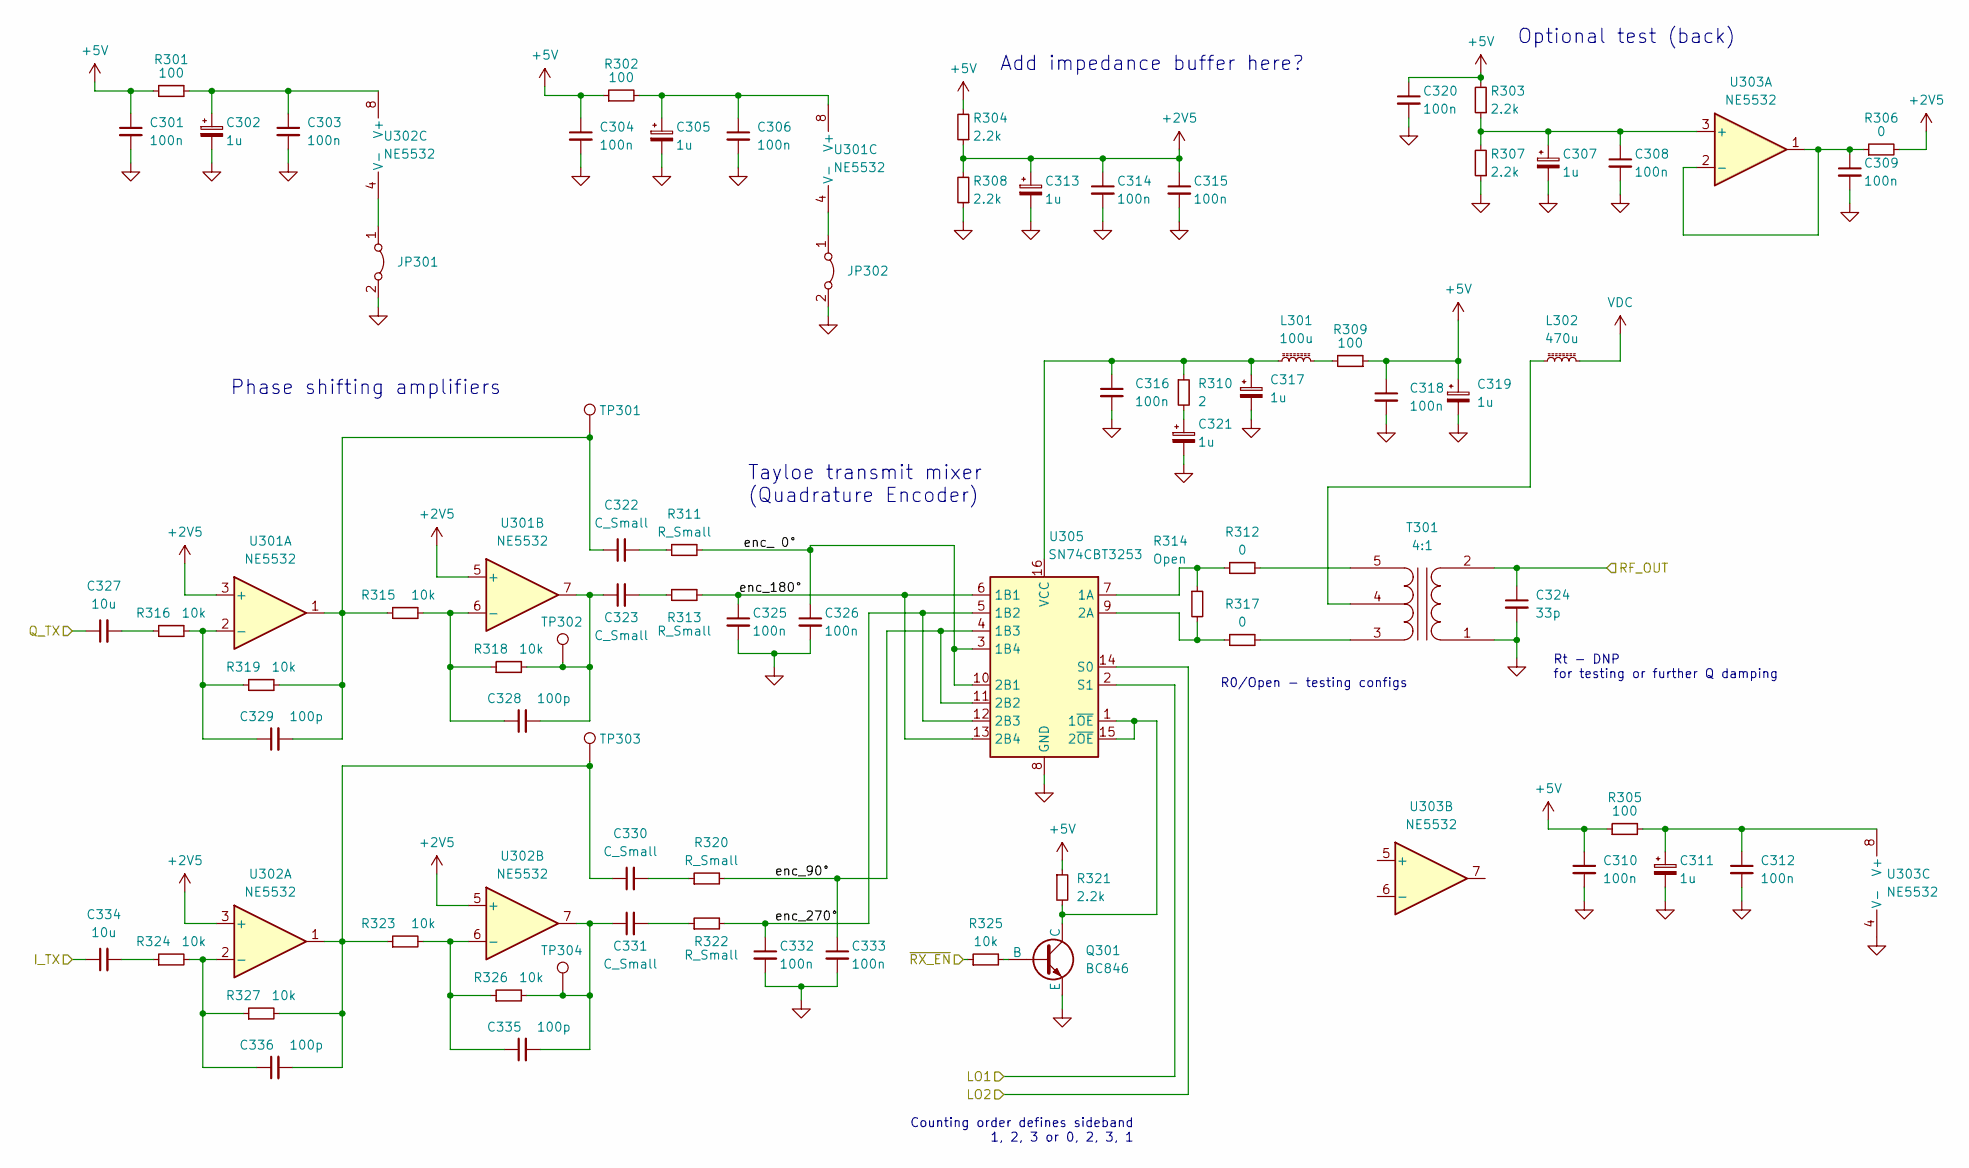
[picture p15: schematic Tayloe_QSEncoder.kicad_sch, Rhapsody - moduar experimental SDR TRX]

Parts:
C301, C303, C304, C306, C308, C309, C310, C312, C314, C315, C316, C318, C320: 100n; C_0603_1608Metric_Pad1.08x0.95mm_HandSolder
C302, C305, C307, C311, C313, C317, C319, C321: 1u; C_0603_1608Metric_Pad1.08x0.95mm_HandSolder
C322, C323, C330, C331: C_Small; C_1206_3216Metric_Pad1.33x1.80mm_HandSolder
C324: 33p; C_0805_2012Metric_Pad1.18x1.45mm_HandSolder
C325, C326, C332, C333: 100n; C_1206_3216Metric_Pad1.33x1.80mm_HandSolder
C327, C334: 10u; C_1206_3216Metric_Pad1.33x1.80mm_HandSolder
C328, C329, C335, C336: 100p; C_1206_3216Metric_Pad1.33x1.80mm_HandSolder
JP301, JP302: Jumper_2_Bridged; R_0805_2012Metric_Pad1.20x1.40mm_HandSolder
L301: 100u; L_1206_3216Metric_Pad1.22x1.90mm_HandSolder
L302: 470u; L_1206_3216Metric_Pad1.22x1.90mm_HandSolder
Q301: BC846; SOT-23-3
R301, R305, R309: 100; R_0603_1608Metric_Pad0.98x0.95mm_HandSolder
R302: 100; R_0805_2012Metric_Pad1.20x1.40mm_HandSolder
R303, R304, R307, R308, R321: 2.2k; R_0603_1608Metric_Pad0.98x0.95mm_HandSolder
R306, R312, R317: 0; R_1206_3216Metric_Pad1.30x1.75mm_HandSolder
R310: 2; R_0603_1608Metric_Pad0.98x0.95mm_HandSolder
R311, R313, R320, R322: R_Small; R_1206_3216Metric_Pad1.30x1.75mm_HandSolder
R314: Open; R_1206_3216Metric_Pad1.30x1.75mm_HandSolder
R315: 10k; R_1206_3216Metric
R316, R323, R324, R326, R327: 10k; R_1206_3216Metric_Pad1.30x1.75mm_HandSolder
R318, R319: 10k; C_1206_3216Metric_Pad1.33x1.80mm_HandSolder
R325: 10k; R_0603_1608Metric_Pad0.98x0.95mm_HandSolder
T301: 4:1; T37_toroid
TP301, TP302, TP303, TP304: TestPoint; TestPoint_Pad_D1.5mm
U301, U302, U303: NE5532; SOIC-8_3.9x4.9mm_P1.27mm
U305: SN74CBT3253; SOIC-16_4.55x10.3mm_P1.27mm

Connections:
+2V5: C313.1, C314.1, C315.1, R304.1, R306.2, R308.2, U301.3 (+), U301.5 (+), U302.3 (+), U302.5 (+)
+5V: C301.1, C304.1, C310.1, C318.1, C319.1, C320.1, R301.1, R302.1, R303.2, R304.2, R305.1, R309.1, R321.1; also elsewhere on the board
/PCIE_Connector/GPIO_14: R325.1; also elsewhere on the board
/TX_QSE/I_TX: C334.1; also elsewhere on the board
/TX_QSE/Q_TX: C327.1; also elsewhere on the board
/TX_QSE/RF_OUT: C324.1, T301.2 (AA); also elsewhere on the board
/TX_QSE/enc_90°: C333.1, R320.2, U305.4 (1B3), U305.11 (2B2)
/TX_QSE/enc_180°: C325.1, R313.2, U305.6 (1B1), U305.13 (2B4)
/TX_QSE/enc_270°: C332.1, R322.2, U305.5 (1B2), U305.12 (2B3)
/TX_QSE/enc_ 0°: C326.1, R311.2, U305.3 (1B4), U305.10 (2B1)
GND: C301.2, C302.2, C303.2, C304.2, C305.2, C306.2, C307.2, C308.2, C309.2, C310.2, C311.2, C312.2, C313.2, C314.2, C315.2, C316.2, C317.2, C318.2, C319.2, C320.2, C321.2, C324.2, C325.2, C326.2, C332.2, C333.2, JP301.2 (B), JP302.2 (B), Q301.2 (E), R307.1, R308.1, T301.1 (AB), U303.4 (V-), U305.8 (GND); also elsewhere on the board
unnamed: C321.1, R310.2
unnamed: C322.1, C329.2, R315.1, R319.2, TP301.1, U301.1
unnamed: C322.2, R311.1
unnamed: C323.1, C328.2, R318.2, TP302.1, U301.7
unnamed: C323.2, R313.1
unnamed: C327.2, R316.1
unnamed: C330.1, C336.2, R323.1, R327.2, TP303.1, U302.1
unnamed: C330.2, R320.1
unnamed: C331.1, C335.2, R326.2, TP304.1, U302.7
unnamed: C331.2, R322.1
unnamed: C334.2, R324.1
unnamed: JP301.1 (A), U302.4 (V-)
unnamed: JP302.1 (A), U301.4 (V-)
unnamed: L301.1, R309.2
unnamed: Q301.1 (B), R325.2
unnamed: Q301.3 (C), R321.2, U305.1 (1~OE), U305.15 (2~OE)
unnamed: R317.2, T301.3 (SA)
unnamed: R312.2, T301.5 (SB)
unnamed: L302.2, T301.4 (SC)
unnamed: C329.1, R316.2, R319.1, U301.2 (-)
unnamed: C328.1, R315.2, R318.1, U301.6 (-)
unnamed: C305.1, C306.1, R302.2, U301.8 (V+)
unnamed: C336.1, R324.2, R327.1, U302.2 (-)
unnamed: C335.1, R323.2, R326.1, U302.6 (-)
unnamed: C302.1, C303.1, R301.2, U302.8 (V+)
unnamed: C307.1, C308.1, R303.1, R307.2, U303.3 (+)
unnamed: C309.1, R306.1, U303.1, U303.2 (-)
unnamed: C311.1, C312.1, R305.2, U303.8 (V+)
unnamed: R312.1, R314.1, U305.7 (1A)
unnamed: R314.2, R317.1, U305.9 (2A)
unnamed: C316.1, C317.1, L301.2, R310.1, U305.16 (VCC)
VDC: L302.1; also elsewhere on the board

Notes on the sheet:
R0/Open - testing configs
Add impedance buffer here?
Optional test (back)
Rt - DNP for testing or further Q damping
Phase shifting amplifiers
Tayloe transmit mixer (Quadrature Encoder)
Counting order defines sideband 1, 2, 3 or 0, 2, 3, 1

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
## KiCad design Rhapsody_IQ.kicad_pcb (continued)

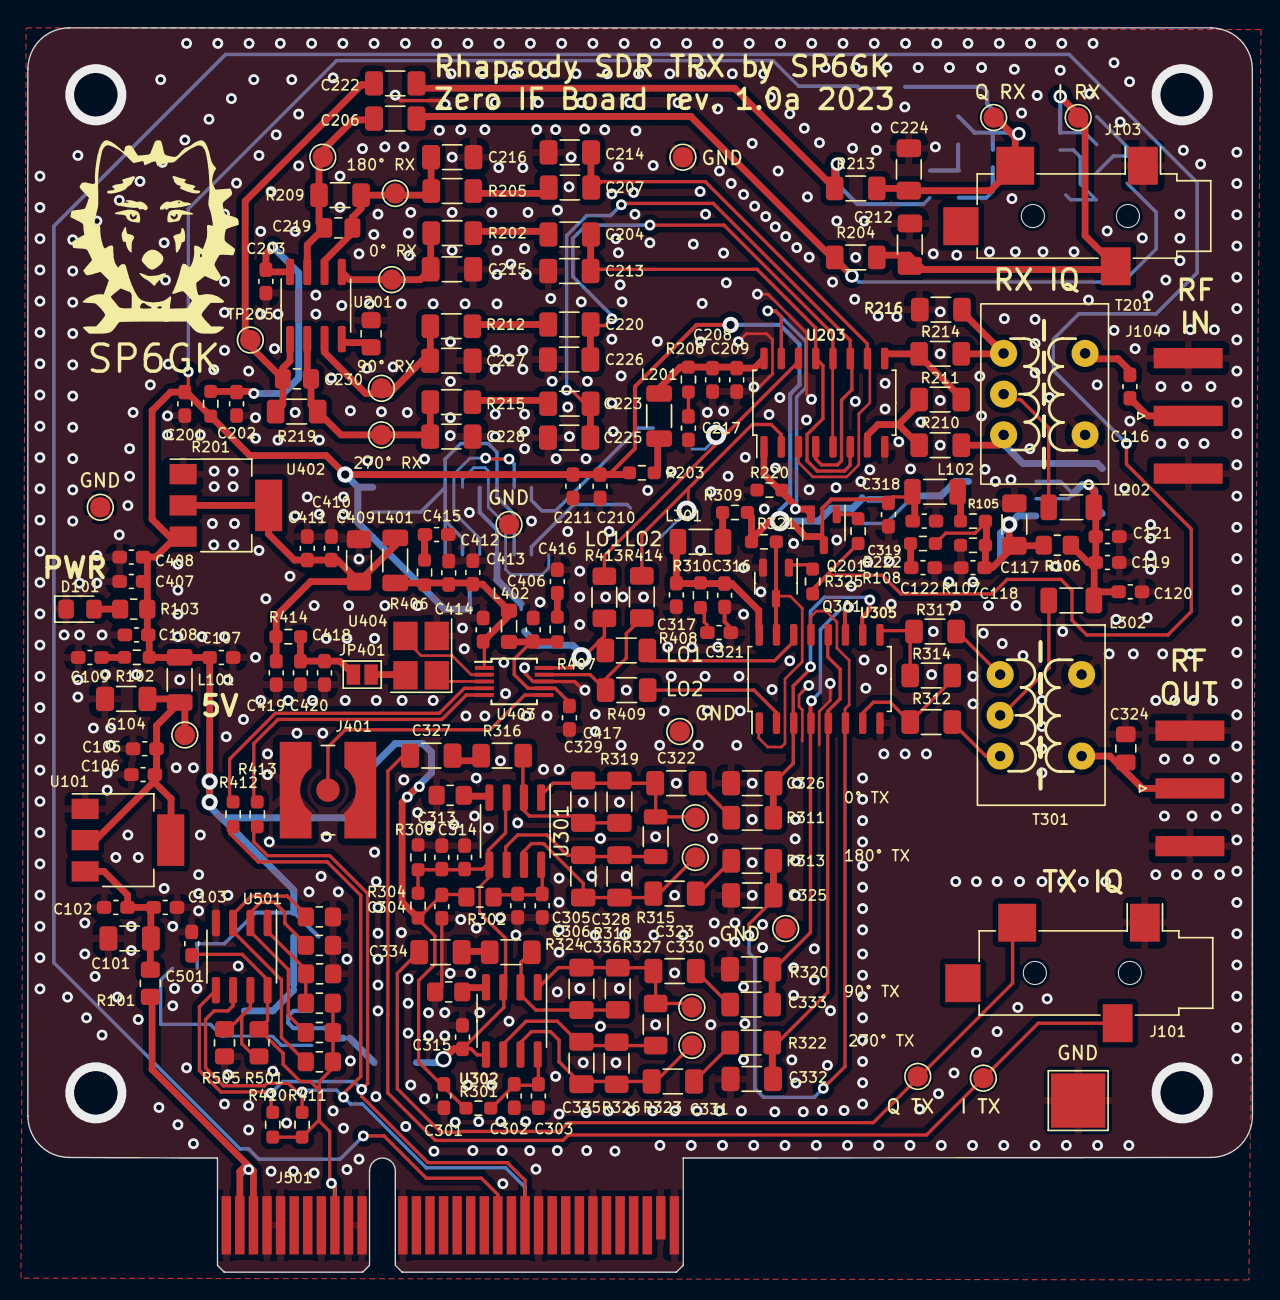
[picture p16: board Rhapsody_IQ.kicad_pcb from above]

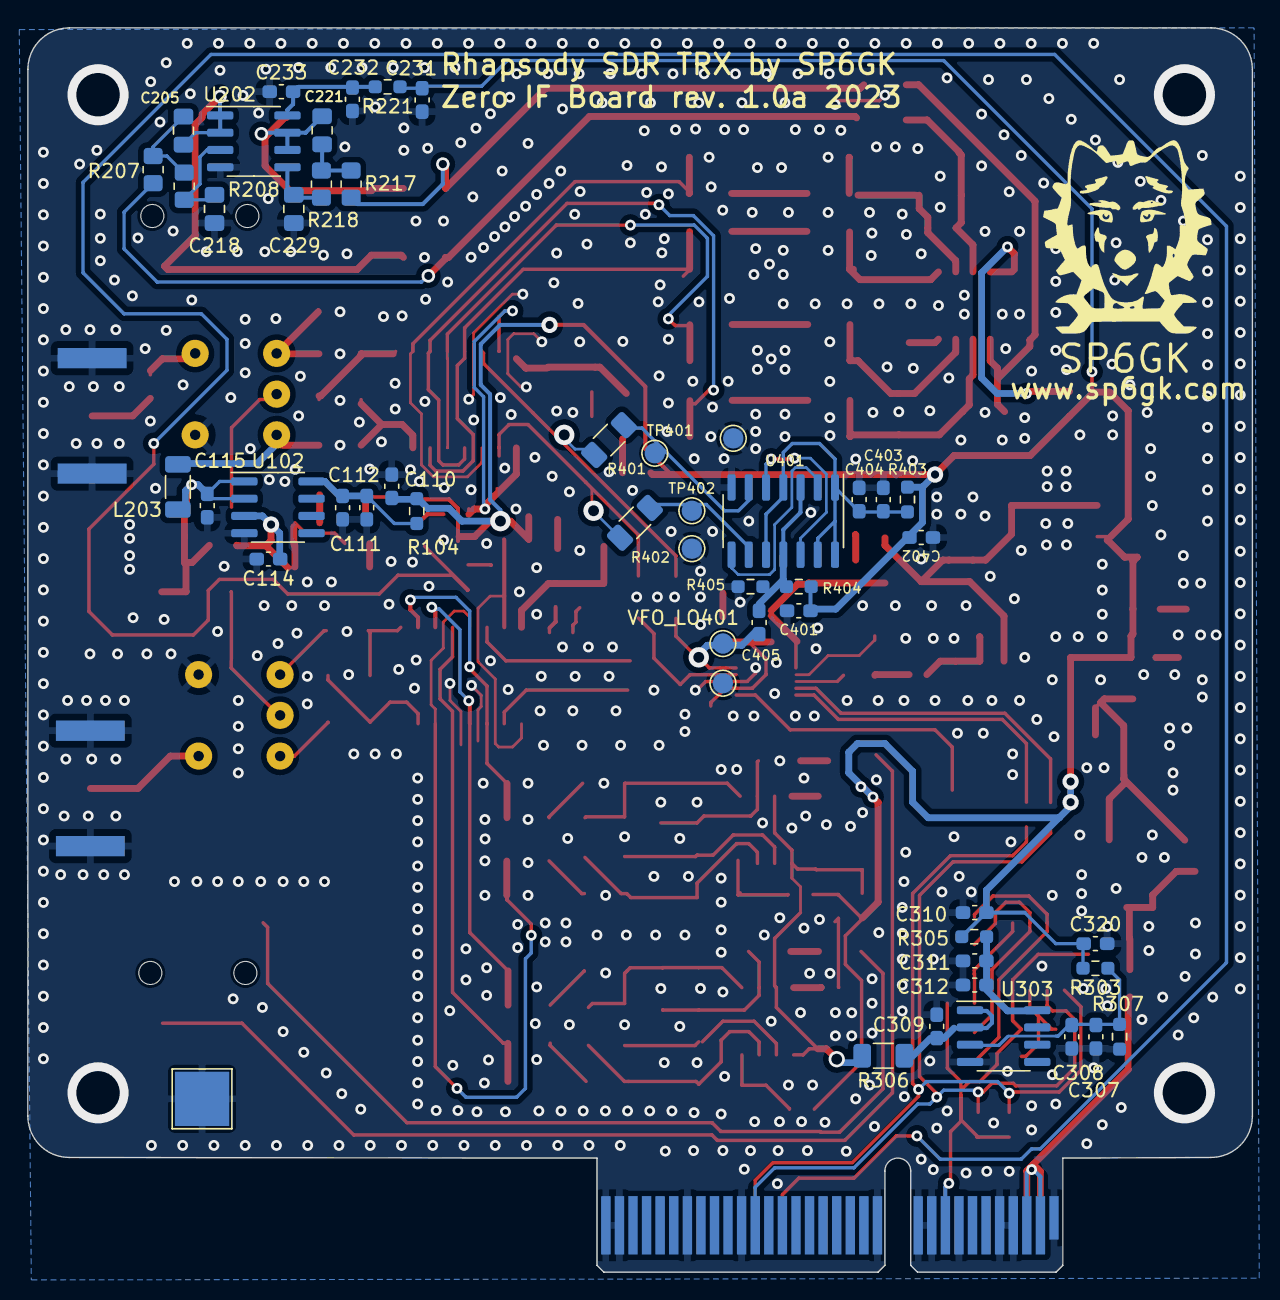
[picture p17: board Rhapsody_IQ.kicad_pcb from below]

Board: 2 copper layers, 90.2 x 91.6 mm, 258 parts (51 on the bottom side), 118 nets.

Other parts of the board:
R413#2: R_Small; R_0603_1608Metric_Pad0.98x0.95mm_HandSolder
R414#2: 100; R_0603_1608Metric_Pad0.98x0.95mm_HandSolder
TP108#2, TP108#3, TP108#4, TP108#5: TestPoint; TestPoint_Pad_D1.5mm

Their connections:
GND: TP108#2.1, TP108#3.1, TP108#4.1, TP108#5.1; also elsewhere on the board
